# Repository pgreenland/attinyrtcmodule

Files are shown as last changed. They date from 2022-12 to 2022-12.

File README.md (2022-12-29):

# ATTinyRTCModule

This repository contains my attempt at a real-time clock (RTC) replacement, specially for the Mac SE/30, untested (yet should work :-P) on others, using the Microchip ATTiny85.

It's specifically aimed at SE/30's that have suffered damage to their RTC circuitry due to battery leaks.

It therefore doesn't require a battery, storing the PRAM contents in the ATTiny's integrated EEPROM.

It also doesn't require a crystal, using the ATTiny's integrated RC oscillator as its clock source.

It should work (although hasn't been tested) in a mac with a working RTC battery. If desired the EEPROM backup of the settings and time can be disabled via commenting out the definition `ENABLE_EEPROM`.

An effort has been made to limit the EEPROM writes. With only updates being written, and update only being considered when the RTC is marked as read-only by the host. However it isn't clear how long the EEPROM will last in the ATTiny's using this approach. Time will tell.

It's based on the good work by other folks:

https://www.reddit.com/r/VintageApple/comments/91e5cf/couldnt_find_a_replacement_for_the_rtcpram_chip/
https://pastebin.com/baPZ4nN4
https://github.com/quorten/macsehw/blob/master/firmware/rtc/MacRTC.c

The ATTiny85 was identified previously as a candidate for a drop-in replacement for some of the classic Mac family of RTC chips.

Previous versions of the firmware focused on the Mac Plus, which has a serial clock of between 1 and 20Khz (based on comments in the code).

The Mac SE/30 has a serial clock of 250Khz, requiring a substantial rewrite to get things working.

This version makes use of the universal serial interface module (USI) to ensure the original timing of the Apple RTC is always met.

My original drop-in replacement attempt [ATTinyRTC](https://github.com/pgreenland/attinyrtc) worked but was often a little close to violating the protocol timing. Using the USI module these problems are avoided and the timings exhibited by the original Apple RTC module are met.

See my blog for additional notes on how the software works / its development:

[New Timepiece for a Classic Mac - Part 1](http://www.quantulum.co.uk/blog/new-timepiece-for-a-classic-mac-part-1/)

[New Timepiece for a Classic Mac - Part 2](http://www.quantulum.co.uk/blog/new-timepiece-for-a-classic-mac-part-2/)

## Hardware

PCB may be ordered from yoru favorite supplier.

The BOM for this project was ordered from RS Components in the UK and consists of the following:

| **Reference** | **Part** | **Quantity** | **RS Part No** |
|---|---|---|---|
| U1 | Microchip ATTINY85-20SU, 8bit AVR Microcontroller, ATtiny85, 20MHz, 8 kB Flash, 8-Pin EIAJ SOIC | 1 | 133-1674 |
| Y1 | Abracon 16MHz Crystal Unit ±20ppm SMD 4-Pin 3.2 x 2.5 x 0.8mm | 1 | 171-2803 |
| C1,C2 | KEMET, 0805 (2012M) 18pF Multilayer Ceramic Capacitor MLCC 50V dc ±5% , SMD C0805C180J5GACTU | 2 | 648-0935 |
| C3 | KYOCERA AVX, 0805 (2012M) 100nF Multilayer Ceramic Capacitor MLCC 50V dc ±10% , SMD 08055C104KAT2A | 1 | 464-6688 |

## Building

1. Ensure avg-gcc, cmake, make and avrdude are installed.

2. Build with cmake
   ```
   cd software
   mkdir build
   cd build
   cmake ..
   make
   ```

3. Flash
   ```
   make upload
   make upload_eeprom
   ```

4. Set fuses
   ```
   make fuses
   ```

### Note

The programmer I'm using is a usbasp programmer, search eBay for USBasp, they all seem pretty much the same. Remember to head over to [USBasp](https://www.fischl.de/usbasp/) to drop them a tip. Alternatively any programmer supported by avrdude can be selected via configuration in the CMake file.

If flashing using the external pins, remember that PB0 and PB1 are swapped (I definately didn't make that mistake).

As part of setting fuses the reset pin is reconfigured as GPIO.

Once this has been done the only way to re-program the chip is by using high voltage programming.

During development, as a workaround I've been re-assigning one of the unused crystal pins to fullfil the role of the PB5, with the help of a small adapter. Thereby allowing standard ICSP programming with no high voltage funny business required.

After the initial programming I found [this guide](https://www.electronics-lab.com/recover-bricked-attiny-using-arduino-as-high-voltage-programmer/) helpful. Using a spare Arduino and minimal components to rewrite the fuses using HV programming, such that the reset pin is again enabled and regular ICSP programming can be performed again.

If resetting fuses using the external pins, note that PB0 and PB1 are swapped as noted above. Also note that PB3 is not accessible via the headers and must be accessed directly on the ATTiny.

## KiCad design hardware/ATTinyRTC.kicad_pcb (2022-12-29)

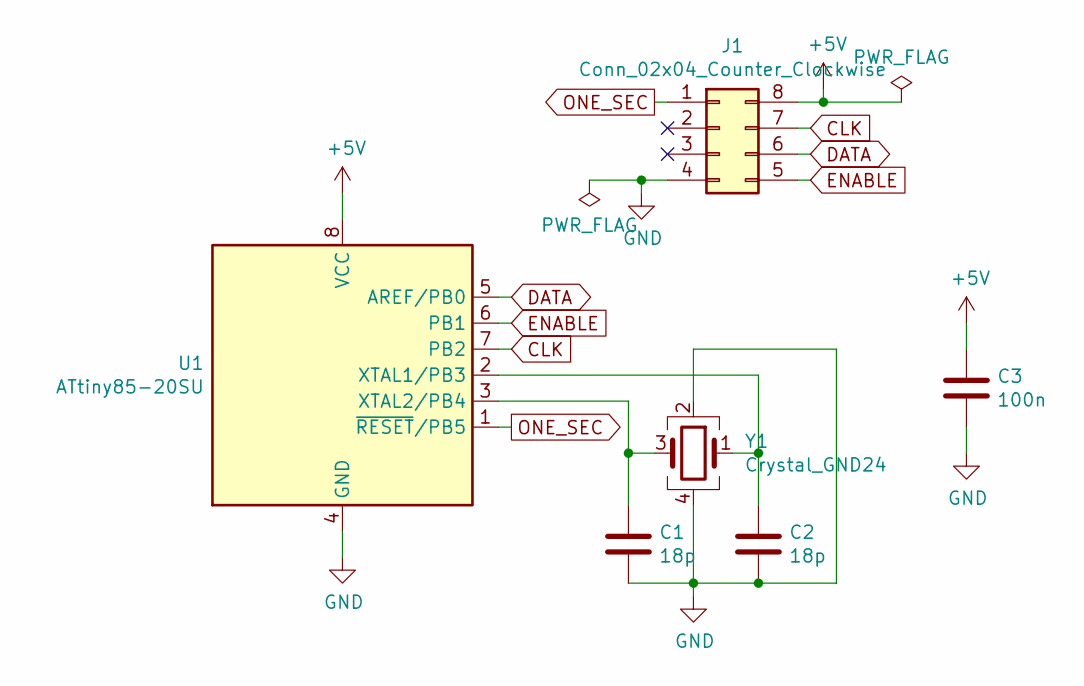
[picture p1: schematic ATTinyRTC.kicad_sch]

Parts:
C1, C2: 18p; C_0805_2012Metric
C3: 100n; C_0805_2012Metric
J1: Conn_02x04_Counter_Clockwise; DIP-8_W7.62mm
U1: ATtiny85-20SU; SOIC-8W_5.3x5.3mm_P1.27mm
Y1: Crystal_GND24; Crystal_SMD_Abracon_ABM8G-4Pin_3.2x2.5mm

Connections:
+5V: C3.1, J1.8, U1.8 (VCC)
CLK: J1.7, U1.7 (PB2)
DATA: J1.6, U1.5 (AREF/PB0)
ENABLE: J1.5, U1.6 (PB1)
GND: C1.2, C2.2, C3.2, J1.4, U1.4 (GND), Y1.2, Y1.4
unnamed: C1.1, U1.3 (XTAL2/PB4), Y1.3
unnamed: C2.1, U1.2 (XTAL1/PB3), Y1.1
ONE_SEC: J1.1, U1.1 (~RESET/PB5)

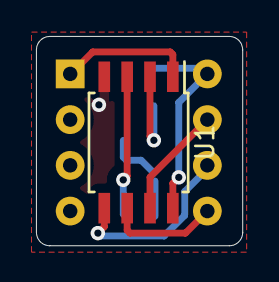
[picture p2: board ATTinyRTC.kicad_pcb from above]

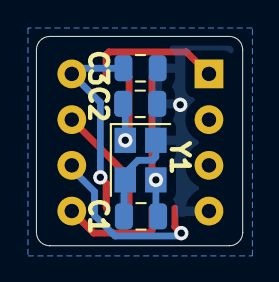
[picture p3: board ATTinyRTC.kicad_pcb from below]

Board: 2 copper layers, 11.5 x 11.6 mm, 6 parts (4 on the bottom side), 8 nets.

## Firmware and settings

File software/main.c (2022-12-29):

/* ------- Config ------- */

/* Enable EEPROM - if defined RTC will backup/restore its data to EEPROM, allowing it to be used in a mac without an RTC battery. Disable for authentic RTC behavior */
#define ENABLE_EEPROM

/* Define to have write only test register readable, returning 0xA5 and 0x5A on alternate reads */
//#define TEST_REG_READ_DUMMY_VALUE

/* Define to output timing pulses on PB3 */
//#define TIMING_ENABLED

/* ---------------------- */

/* Standard libraries */
#include <stdint.h>
#include <stdbool.h>

/* AVR libraries */
#include <avr/io.h>
#include <avr/wdt.h>
#include <avr/interrupt.h>
#include <avr/eeprom.h>
#include <avr/sleep.h>

/* Add section for simulator */
#ifdef BUILD_FOR_SIM
#include "avr/avr_mcu_section.h"
AVR_MCU(F_CPU, "attiny85");
#endif

/*
RTC Pinout -> ATTiny85 pinout
              __  __
 1SEC (PB5) -|1 \/ 8|- VCC
XTAL1 (PB3) -|2    7|- (PB2) RTC.CLK
XTAL2 (PB4) -|3    6|- (PB1) RTC.DATA
        GND -|4____5|- (PB0) !RTC

Note that as the USI hardware is required, RTC.DATA and !RTC (enable) must be swapped.
*/

/*
One second interrupt with 50% duty cycle:

The GPIO interrupt line needs to toggle every 500ms.
Timer 0 prescaler = 1024.

@ 16Mhz clock:
Timer 0 freq = 16e6 / 1024 = 15625Hz
We enable CTC mode, causing the timer to interrupt and reset on a value of our choice.
Timer 0 compare = 125
15625 / 125 = 125Hz (timer interrupt will fire every 8ms)
We wish to toggle every 500ms aka 2Hz.
125 / 2 = 62.5
We therefore need to toggle the output every 62.5 interrupts.
We can scale that number up to an integer
62.5 * 2 = 125
Each time we receive an interrupt we add 2 to a counter.
Whenever the counter is >= 125 we decrement it by 125 and toggle the output.

We use the timer to monitor serial commands for timeouts. Given that each tick
is 64us, the longest serial transaction is ~100us we'll wait 4 ticks before aborting.
This ensures that if the system is powered down (with a battery), when the enable
line goes low following power loss the interrupt will abort and wait for power to
be applied still.
*/

/*
Regular command / address is
uVVVVVww
Where
	u = 0 for write and x = 1 for read
	VVVVV = Regular addr (table below)
	ww = 01 for regular command, don't care for extended

If Regular Command Addr = 0x0e or 0x0f, command is extended and next byte is an extended address
	xYYYYYzz
Where
	x = Don't care
	YYYYY = Extended address, least significant 5 bytes
	zz = Don't care

Full extended address may be formed by:
	(Vww << 5) | YYYYY
	That is the lowest order 3 bits from regular command / address and extended address bits

An 8-bit data byte follows the regular / extended command bytes, send by the host (if write) or device (if read)

Classic PRAM is 20 bytes (+ 4 bytes for clock).
	00 = Clock 0
	01 = Clock 1
	02 = Clock 2
	03 = Clock 3
	04 = Clock 0
	05 = Clock 1
	06 = Clock 2
	07 = Clock 3
	08 = RAM Lo
	09 = RAM Lo
	0A = RAM Lo
	0B = RAM Lo
	0C = Test reg
	0D = Write protect
	0E = Extended cmd
	0F = Extended cmd
	10 = RAM Hi
	11 = RAM Hi
	12 = RAM Hi
	13 = RAM Hi
	14 = RAM Hi
	15 = RAM Hi
	16 = RAM Hi
	17 = RAM Hi
	18 = RAM Hi
	19 = RAM Hi
	1A = RAM Hi
	1B = RAM Hi
	1C = RAM Hi
	1D = RAM Hi
	1E = RAM Hi
	1F = RAM Hi

Extended PRAM is 256 bytes (+ 4 bytes for clock):
	0x08 - 0x0B = RAM Lo mirror
	0x10 - 0x1F = RAM Hi mirror
*/

/* Define fuse config */
FUSES = {
	/* Use 16 MHz external crystal, disabling divide by 8. */
	.low = (LFUSE_DEFAULT | ~FUSE_CKDIV8 | ~FUSE_CKSEL3 | ~FUSE_CKSEL2),

	/* Disable the external RESET pin since it is used for the 1-second interrupt output. */
	.high = (HFUSE_DEFAULT & FUSE_RSTDISBL),

	/* Extended fuse takes default value */
	.extended = EFUSE_DEFAULT
};

/* Types */
typedef union
{
	/* Value for incrementing */
	uint32_t uiValue;

	/* 8-bit AVR is modelled as little endian by GCC at least, access bytes directly */
	uint8_t abyValue[4];

} uSeconds_t;

/* Define pins */
static const uint8_t uiPinData = PB0;
static const uint8_t uiPinEnable = PB1;
static const uint8_t uiPinOneSec = PB5;

/* Hijack one of the crystal pins for some logic analyzer snoopage */
#ifdef TIMING_ENABLED
static const uint8_t uiPinTiming = PB3;
#endif

/* Define pin change interrupts to match enable pin above */
static const uint8_t uiChangeIntEnable = PCINT1;

/* Check supported clock frequency for timer calculations */
#if F_CPU != 16000000
#error "Unexpected clock frequency"
#endif

/* One second timer divider */
static const uint8_t uiTimerDivider = 125;

/* One second timer counter increment */
static const uint8_t uiCounterInc = 2;

/* One second timer match */
static const uint8_t uiCounterMatch = 125;

/* Serial timeout count */
static const uint8_t uiTimeoutCount = 4;

/* Macros */

/* Check if inputs are high */
#define mIsEnableHigh() (0 != (PINB & _BV(uiPinEnable)))

/* Check if timeout timer has expired */
#define mSerialTimeout() (TIFR & _BV(OCF0B))

/* Reset USI counter overflow flag */
#define mResetUSIOIF() asm volatile("sbi %[reg], %[bit]" : /* no out */ : [reg] "I" (_SFR_IO_ADDR(USISR)), [bit] "I" (USIOIF))

/* Check if USI counter overflow flag is set */
#define mIsUSIOIFSet() (0 != (USISR & _BV(USIOIF)))

/* Check if base address is special extended address value */
#define mIsAddrExtended(base) (0x38 == ((base) & 0x78))

/* Check if base address has write flag set */
#define mIsAddrWrite(base) (0 == ((base) & 0x80))

/* Extract address from regular / extended command */
#define mExtractBaseAddr(base) (((base) & 0x7C) >> 2)
#define mExtractExtendedAddr(base, ext) ((((base) & 0x07) << 5) | (((ext) & 0x7C) >> 2))

/* Check if regular address is within clock range */
#define mIsClockAddr(base) ((base) >= 0x00 && (base) <= 0x07)

/* Check if regular address is within low or high RAM range */
#define mIsRAMLoAddr(base) ((base) >= 0x08 && (base) <= 0x0B)
#define mIsRAMHiAddr(base) ((base) >= 0x10 && (base) <= 0x1F)

/* Check if regular address is for (write only) write protect register */
#define mIsWriteProtectAddr(base) (0x0D == (base))

/* Check if write protect data bit is set */
#define mDataByteToWriteProtect(data) (0 != ((data) & 0x80))

/* Check if regular address is for (write only) test register */
#define mIsTestAddr(base) (0x0C == (base))

/* Clock bytes are duplicated, work out which byte is being read or written */
#define mClockByte(base) ((base) & 0x03)

/* Change timing pin outputs */
#ifdef TIMING_ENABLED
	#define mTimingPinLow() asm volatile("sbi %[ddrb], %[pin]" : /* no out */ : [ddrb] "I" (_SFR_IO_ADDR(DDRB)), [pin] "I" (uiPinTiming));
	#define mTimingPinHigh() asm volatile("cbi %[ddrb], %[pin]" : /* no out */ : [ddrb] "I" (_SFR_IO_ADDR(DDRB)), [pin] "I" (uiPinTiming));
#else
	#define mTimingPinLow()
	#define mTimingPinHigh()
#endif

/* Define PRAM size */
#define PRAM_SIZE (256) /* bytes */

/* Function prototypes */
static void powerSaveInit(void);
static void gpioInit(void);
static void usiInit(void);
static void timerInit(void);
static uint8_t processRegularCmdRead(uint8_t uiAddrBase);
static void processRegularCmdWrite(uint8_t uiAddrBase, uint8_t uiData);
static uint8_t processExtendedCmdRead(uint8_t uiAddrBase, uint8_t uiAddrExt);
static void processExtendedCmdWrite(uint8_t uiAddrBase, uint8_t uiAddrExt, uint8_t uiData);

#ifdef ENABLE_EEPROM

/* PRAM EEPROM buffer */
__attribute__((section(".eeprom")))
static uint8_t abyPRAM[PRAM_SIZE] = {0x00};

/* Clock EEPROM buffer */
__attribute__((section(".eeprom")))
static uint32_t uiStoredSeconds = 0;

#endif

/* PRAM shadow buffer (working copy of EEPROM data in RAM) */
static uint8_t abyPRAMShadow[PRAM_SIZE];

#ifdef ENABLE_EEPROM

/*
** Dirty flag - Set when PRAM shadow write protection applied. Ideally this would
** only be set if a value was written, however this way we get a free flush of the
** clock when shutting down. The EEPROM is only written if it changes so we should
** be ok....maybe....hopefully....
*/
static volatile bool bShadowDirty;

#endif

/* Write protection status */
static bool bWriteProtected = true;

/* Seconds counter */
static volatile uSeconds_t uSeconds;

int main(void)
{
	/* Disable interrupts */
	cli();

	/* Disable unused peripherals to save power */
	powerSaveInit();

	/* Init peripherals */
	timerInit();
	gpioInit();
	usiInit();

#ifdef ENABLE_EEPROM
	/* Load PRAM shadow from EEPROM */
	eeprom_read_block(abyPRAMShadow, abyPRAM, sizeof(abyPRAMShadow));

	/* Load last time from EEPROM */
	uSeconds.uiValue = eeprom_read_dword(&uiStoredSeconds);
#endif

	/* Enable interrupts */
	sei();

	/* Sleep whenever possible, updating EEPROM if dirty */
	for (;;)
	{
#ifdef ENABLE_EEPROM
		if (bShadowDirty)
		{
			/* Clear dirty flag first in case its set again */
			bShadowDirty = false;

			/* Update PRAM in EEPROM from shadow in RAM */
			eeprom_update_block(abyPRAMShadow, abyPRAM, sizeof(abyPRAMShadow));

			/* Sample clock via repeated read, to avoid having to disable interrupts */
			uint32_t uiTmpSeconds;
			do
			{
				uiTmpSeconds = uSeconds.uiValue;
			} while (uiTmpSeconds != uSeconds.uiValue);

			/* Update clock in EEPROM from RAM */
			eeprom_update_dword(&uiStoredSeconds, uiTmpSeconds);
		}
#endif

		/* Go back to sleep */
		sleep_mode();
	}
}

/* Flag ISR with ISR_NOBLOCK, such that interrupts will be re-enabled allowing higher priority serial interrupt to nest with less critical timer */
ISR(TIM0_COMPA_vect, ISR_NOBLOCK)
{
	static uint8_t uiCounter;

	/* Count match */
	uiCounter += uiCounterInc;

	/* Check counter */
	if (uiCounter >= uiCounterMatch)
	{
		/* Toggle one second line */
		DDRB ^= _BV(uiPinOneSec);

		/* Increment seconds counter every other toggle */
		if (DDRB & _BV(uiPinOneSec))
		{
			/* Atomically increment seconds */
			cli();
			uSeconds.uiValue++;
			sei();
		}

		/* Decrement counter */
		uiCounter -= uiCounterMatch;
	}
}

ISR(PCINT0_vect)
{
	/* Serial address (base and extended) */
	uint8_t uiAddrBase = 0;
	uint8_t uiAddrExt = 0;

	/* Serial data */
	uint8_t uiData = 0;

	/* Rising edge on enable (chip deselected), stop early */
	if (mIsEnableHigh())
	{
		/* Reset USI counter and interrupt flag to catch start of next command */
		USISR = _BV(USIOIF);
		mTimingPinHigh();
		return;
	}

	/* Configure Timer0 match B to timeout transfer */
	mTimingPinLow();
	uint8_t uiTimeoutMatch = TCNT0 + uiTimeoutCount;
	if (uiTimeoutMatch >= uiTimerDivider) uiTimeoutMatch -= uiTimerDivider;
	OCR0B = uiTimeoutMatch;
	TIFR = _BV(OCF0B);
	mTimingPinHigh();

	/* Read command / address byte, wait for read to complete while monitoring enable */
	mTimingPinLow();
	while (!mIsUSIOIFSet()) if (mIsEnableHigh() || mSerialTimeout())
	{
		/* Enable de-asserted or timeout, clear timing pin and return */
		mTimingPinHigh();
		return;
	}
	uiAddrBase = USIBR;
	mTimingPinHigh();

	/* Check if extended command */
	if (mIsAddrExtended(uiAddrBase))
	{
		/* Receive extended address, wait for read to complete while monitoring enable */
		mTimingPinLow();
		mResetUSIOIF();
		while (!mIsUSIOIFSet()) if (mIsEnableHigh() || mSerialTimeout())
		{
			/* Enable de-asserted or timeout, clear timing pin and return */
			mTimingPinHigh();
			return;
		}
		uiAddrExt = USIBR;
		mTimingPinHigh();
	}

	/* Check if write */
	if (mIsAddrWrite(uiAddrBase))
	{
		/* Write request, receive data, wait for read to complete while monitoring enable */
		mTimingPinLow();
		mResetUSIOIF();
		while (!mIsUSIOIFSet()) if (mIsEnableHigh() || mSerialTimeout())
		{
			/* Enable de-asserted or timeout, clear timing pin and return */
			mTimingPinHigh();
			return;
		}
		uiData = USIBR;
		mTimingPinHigh();

		/* Execute command */
		mTimingPinLow();
		if (mIsAddrExtended(uiAddrBase))
		{
			/* Execute extended command */
			processExtendedCmdWrite(uiAddrBase, uiAddrExt, uiData);
		}
		else
		{
			/* Execute regular command */
			processRegularCmdWrite(uiAddrBase, uiData);
		}
		mTimingPinHigh();
	}
	else
	{
		/*
		** Read request
		** This is the most time critical section of the ISR
		** We have to decode the address and fetch the correct register
		** placing it back in the USI data buffer before the next rising
		** clock edge. While the clock is low the output latch is enabled
		** such that whatever is in the msb of the data register is
		** presented on the data line. When the clock rises, the latch is
		** disabled and the register shifted. We pre-set the bit counter
		** to one, allowing us to miss the falling edge of the clock.
		** When the overflow is detected, we'll wait for enable to go high
		** allowing the USI module to shift the final data bit out.
		** At the same time, clear the overflow flag
		*/
		USISR = _BV(USIOIF) | 0x01;

		mTimingPinLow();
		if (mIsAddrExtended(uiAddrBase))
		{
			/* Execute extended command */
			uiData = processExtendedCmdRead(uiAddrBase, uiAddrExt);
		}
		else
		{
			/* Execute regular command */
			uiData = processRegularCmdRead(uiAddrBase);
		}
		mTimingPinHigh();

		/* Send data, load byte (returned from read) into data register */
		USIDR = uiData;

		/* Enable pullup (allowing USI to drive line) and set line as output */
		PORTB |= _BV(uiPinData);
		DDRB |= _BV(uiPinData);

		/* Wait for write to complete */
		mTimingPinLow();
		while (!mIsUSIOIFSet()) if (mIsEnableHigh() || mSerialTimeout()) break;
		mTimingPinHigh();

		/* Wait for enable to go high (hopefully after write completes) */
		while (!mIsEnableHigh() && !mSerialTimeout());

		/* Disable pullup (allowing USI to drive line) and set line as input */
		DDRB &= ~_BV(uiPinData);
		PORTB &= ~_BV(uiPinData);
	}
}

static void powerSaveInit(void)
{
	/* Disable watchdog */
	wdt_disable();

	/* Disable Analog Comparator */
	ACSR |= _BV(ACD);

	/* Disable Timer 1, only using Timer 0 */
	PRR |= _BV(PRTIM1);

	/* Disable Analog/Digital Converter */
	PRR |= _BV(PRADC);
}

static void gpioInit(void)
{
	/* Enable pin change interrupt for enable */
	GIMSK |= _BV(PCIE);
	PCMSK |= _BV(uiChangeIntEnable);
}

static void usiInit(void)
{
	/*
	** Set USI into two wire mode, with external clock, sampling on rising edge, incrementing
	** counter on both edges.
	*/
	USICR = (1 << USIWM1) | (0 << USIWM0) | (1 << USICS1) | (0 << USICS0) | (0 << USICLK);
}

static void timerInit(void)
{
	/* Enable CTC mode (clear timer on compare match) */
	TCCR0A = (1 << WGM01) | (0 << WGM00);
	TCCR0B = (0 << WGM02);

	/* Set prescaler to 1024 */
	TCCR0B |= (1 << CS02) | (0 << CS01) | (1 << CS00);

	/* Divide by uiTimerDivider (matching on limit - 1) */
	OCR0A = uiTimerDivider - 1;

	/* Enable timer 0 output compare match A interrupt */
	TIMSK |= _BV(OCIE0A);
}

static inline uint8_t processRegularCmdRead(uint8_t uiAddrBase)
{
	/* Prepare full address */
	uint8_t uiFullAddr = mExtractBaseAddr(uiAddrBase);

	if (mIsClockAddr(uiFullAddr))
	{
		/* Clock address, decide on byte to get or set (given clock is repeated) */
		uint8_t uiByteIndex = mClockByte(uiFullAddr);

		/* Retrieve byte */
		return uSeconds.abyValue[uiByteIndex];
	}
	else if (	mIsRAMLoAddr(uiFullAddr)
			 || mIsRAMHiAddr(uiFullAddr)
			)
	{
		/* RAM address is within classic low or high range, which maps directly into extended range, retrieve byte */
		return abyPRAMShadow[uiFullAddr];
	}
	#ifdef TEST_REG_READ_DUMMY_VALUE
	else if (mIsTestAddr(uiFullAddr))
	{
		static uint8_t uiTestRegVal = 0x5A;

		/* Invert bits */
		uiTestRegVal = ~uiTestRegVal;

		/* Return value */
		return uiTestRegVal;
	}
	#endif

	/* If we got this far, address was rejected, return bus idle value */
	return 0xFF;
}

static inline void processRegularCmdWrite(uint8_t uiAddrBase, uint8_t uiData)
{
	/* Prepare full address */
	uint8_t uiFullAddr = mExtractBaseAddr(uiAddrBase);

	/* Check if write protected when writing */
	if (	bWriteProtected
		 && !mIsWriteProtectAddr(uiFullAddr)
	   )
	{
		/*
		** Write request while write protected, to a register other than the
		** write protect register, ignore
		*/
		return;
	}

	if (mIsClockAddr(uiFullAddr))
	{
		/* Clock address, decide on byte to get or set (given clock is repeated) */
		uint8_t uiByteIndex = mClockByte(uiFullAddr);

		/* Retrieve byte */
		uSeconds.abyValue[uiByteIndex] = uiData;
	}
	else if (mIsWriteProtectAddr(uiFullAddr))
	{
		/* Extract new write protect status */
		bool bNewWriteProtected = mDataByteToWriteProtect(uiData);

#ifdef ENABLE_EEPROM
		/* Set dirty flag when transitioning from read-write to read-only */
		if (!bWriteProtected && bNewWriteProtected) bShadowDirty = true;
#endif

		/* Update write protect flag */
		bWriteProtected = bNewWriteProtected;
	}
	else if (	mIsRAMLoAddr(uiFullAddr)
			 || mIsRAMHiAddr(uiFullAddr)
			)
	{
		/* RAM address is within classic low or high range, which maps directly into extended range, store byte */
		abyPRAMShadow[uiFullAddr] = uiData;
	}
}

static inline uint8_t processExtendedCmdRead(uint8_t uiAddrBase, uint8_t uiAddrExt)
{
	/* Prepare full address */
	uint8_t uiFullAddr = mExtractExtendedAddr(uiAddrBase, uiAddrExt);

	/* Retrieve data */
	return abyPRAMShadow[uiFullAddr];
}

static inline void processExtendedCmdWrite(uint8_t uiAddrBase, uint8_t uiAddrExt, uint8_t uiData)
{
	/* Prepare full address */
	uint8_t uiFullAddr = mExtractExtendedAddr(uiAddrBase, uiAddrExt);

	/* Prevent write if write protection enabled */
	if (bWriteProtected) return;

	/* Store data */
	abyPRAMShadow[uiFullAddr] = uiData;
}
